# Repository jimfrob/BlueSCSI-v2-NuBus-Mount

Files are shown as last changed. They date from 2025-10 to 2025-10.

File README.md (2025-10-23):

# BlueSCSI-v2-NuBus-Mount

Being unable to find a design that allowed for mounting a BlueSCSI directly in a NuBus slot (existing models were only for an SD card extension), I decided to take two relevant models and modify them to do so.

My first attempt ended up only being compatible with the larger Macintosh II style slot. These files are located in the Macintosh II folder.

The bracket I modified can be found at https://www.printables.com/model/849210-bluescsi-v2-50-pin-desktop-universal-mount

The NuBus shield I modified can be found at https://github.com/alxlab-zone66x/Reference_Design_Library/tree/main/Connector%20Shield%20for%20Macintosh%20II-Family%20Computer

Since that first model wasn't compatible with my Quadra 650, I started over from scratch. These files are located in the Quadra folder.

I still used the same Universal BlueSCSI v2 mount, but I used the slot cover found at https://www.printables.com/model/1223206-macintosh-quadraiiciiicx-nubus-slot-cover/files and modified it to remove the clips and add an SD card slot. I then created an extension that fits snugly over the NuBus connector and then is connected to the adapter with an M3 bolt (for self-tapping) or M2.5x15 bolt with a nut. This single point of attachment allows the extension to pivot out of the way while angling the adapter into the slot. Everything should line up well once the extension is pressed onto the NuBus connector.

In both cases, I did my best to align everything by using an STL generated from the KiCad PCB editor from the files from the BlueSCSI v2 GitHub page (https://github.com/BlueSCSI/BlueSCSI-v2)

I will include my Bambu Studio project files as well as the STLs of the extensions I made in FreeCAD for the bracket.

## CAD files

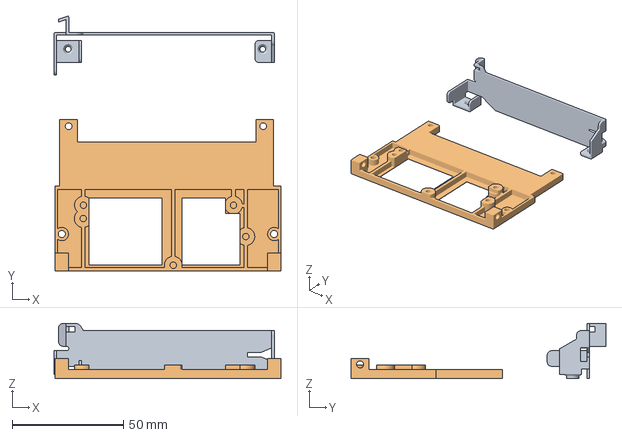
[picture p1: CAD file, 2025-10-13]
Macintosh II/BlueSCSI-NuBus-Mount.3mf
101.8 x 114.2 x 24.8 mm
Assembly
Sub-merged body

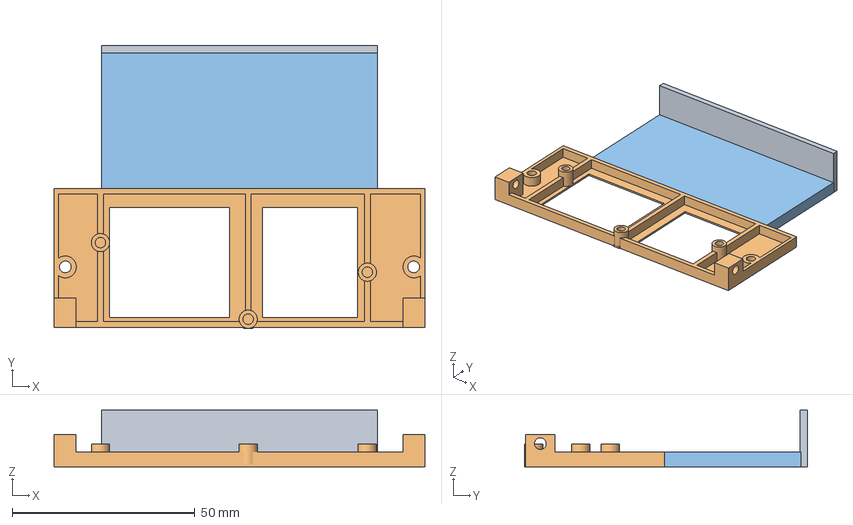
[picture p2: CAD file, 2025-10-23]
Quadra/Quadra 650 BlueSCSI NuBus.3mf
101.4 x 77.3 x 15.5 mm
nubus-slot-cover-quadra.stl
Assembly

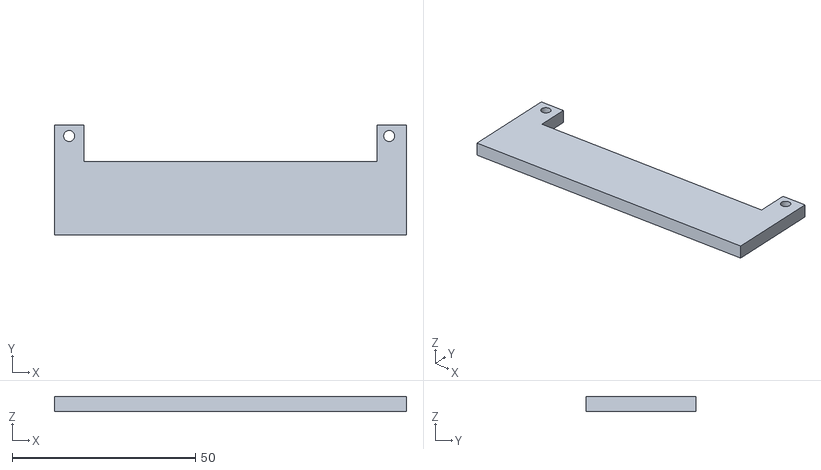
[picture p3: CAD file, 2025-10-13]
Macintosh II/BlueSCSI-Extension.stl
96.0 x 30.0 x 4.00

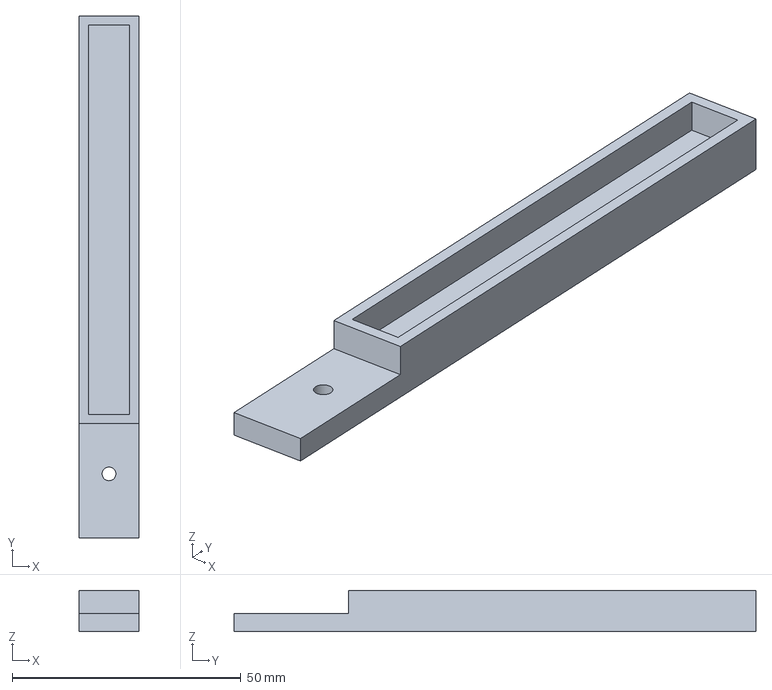
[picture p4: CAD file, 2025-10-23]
Quadra/BlueSCSI Mount Extension.FCStd
13.0 x 114.0 x 9.00 mm

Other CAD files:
Quadra/BlueSCSI Mount Extension.stl

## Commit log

2025-10-23 Rename BlueSCSI-Extension.stl to Macintosh II/BlueSCSI-Extension.stl
    Moved to new directory
    [BlueSCSI-Extension.stl]
2025-10-23 Rename BlueSCSI-NuBus-Mount.3mf to Macintosh II/BlueSCSI-NuBus-Mount.3mf
    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
    [BlueSCSI-NuBus-Mount.3mf]
